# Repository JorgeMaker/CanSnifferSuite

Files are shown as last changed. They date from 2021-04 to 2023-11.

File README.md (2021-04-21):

<p align="center">
  
</p>

# CanSnifferSuite

Blue Pill CAN bus dongle is an USB to CAN Bus 2.0A/B adapter that acts as sniffer and traffic generator. This project is composed by three independent building blocks that can be used   in combination or separately.

### Firmware:
Is an application that runs on a STM32F103C8T6 and can be deployed on the [specifically designed PCB](https://github.com/JorgeMaker/CanSnifferSuite/tree/main/hw) for this project or on the popular and fairly affordable Blue Pill adding some extra HW also very cheap and easy to obtain and connect.

In this repository there are a couple of firmware. The first is for Blue Pill and is based on an interrupt driven layout design, the second in case that you prefer to use a STM32F40X family MCU uses the popular FreeRTOS for its implementation.

The [first implementation](https://github.com/JorgeMaker/CanSnifferSuite/tree/main/fw/BluePillCanSnniferEventDriven), the ISRs are responsible for receiving the basic elements of each of the two communication interfaces: the character and the datagram. Once received, they are stored in queues so that from the main function they are processed by applying a round robin algorithm.

<p align="center">
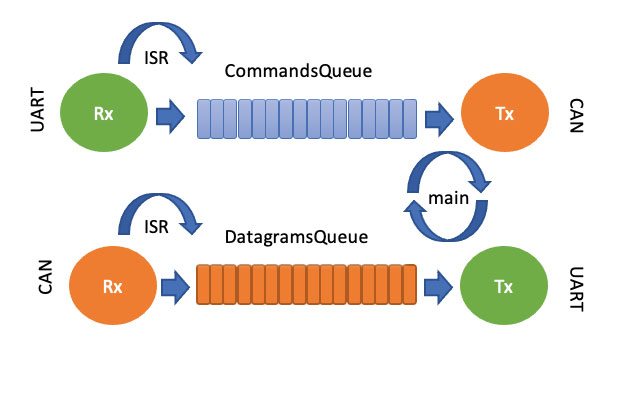
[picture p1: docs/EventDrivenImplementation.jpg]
  
</p>

The [second implementation](https://github.com/JorgeMaker/CanSnifferSuite/tree/main/fw/STM32F407VGT6CanSnniferFreeRTOS), targeted for STM32F40X uses FreeRTOS to achieve the desired functionality. The characters and datagrams received by each communication interface are stored in a pair of queues that are managed by 4 tasks.

<p align="center">
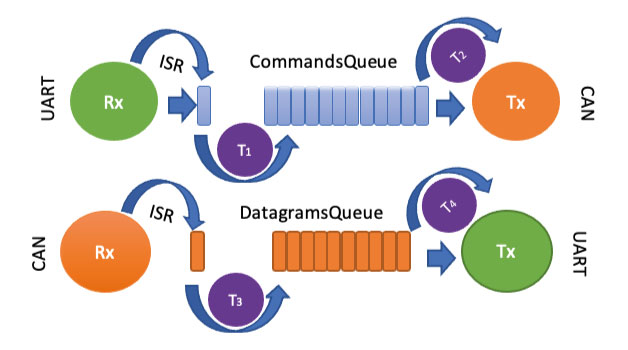
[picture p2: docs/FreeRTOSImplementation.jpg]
  
</p>

Both solutions perform the same function and can be used interchangeably  with the GUI tool and Python library.

###  Hardware:

To implement the [ HW part of the project](https://github.com/JorgeMaker/CanSnifferSuite/tree/main/hw), there are two possible alternatives with exactly the same functionality:

The first and the one the easiest reachable uses the popular very Blue Pill as MCU with an USB to TTL and a CAN bus transceiver. These three elements can be purchased online on shops like AliExpress, Banagood and others. Their combined cost does not exceed € 7, constituting a very affordable solution. There is an interconnection diagram available at the HW folder with [detailed instructions](https://github.com/JorgeMaker/CanSnifferSuite/blob/main/hw/InterconnectionsEasySolution.pdf).

The second alternative is to build custom PCB specific for this project to have a CAN bus dongle.  Geber files, and schematics are provided at the HW folder.

<p align="center">
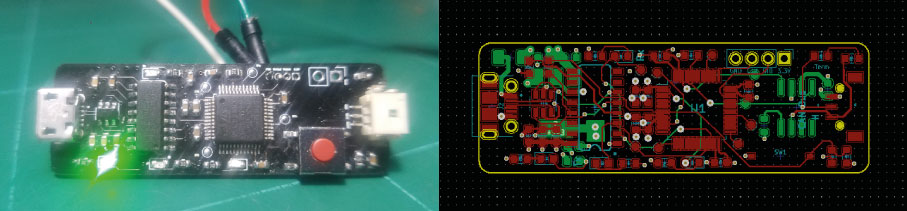
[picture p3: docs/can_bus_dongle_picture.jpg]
  
</p>

- Developed using the popular STM32F103C8T6
- Supports CAN2.0A and B, baud rates up to 500K
- 3 pins Hirose DF13 terminal: CANH, CANL, GND
- 120 Ohm termination via zero ohms resistor to enable/disable
- Tx an Rx LED indicators.
- GUI tool and Python library:

###  GUI tool and Python lib:

An application written in using PyQt/Python  has been developed. It allows communication with the Blue Pill CAN bus dongle to send commands and receive information on the traffic present on the CAN bus network acting as sniffer and traffic generator.

<p align="center">
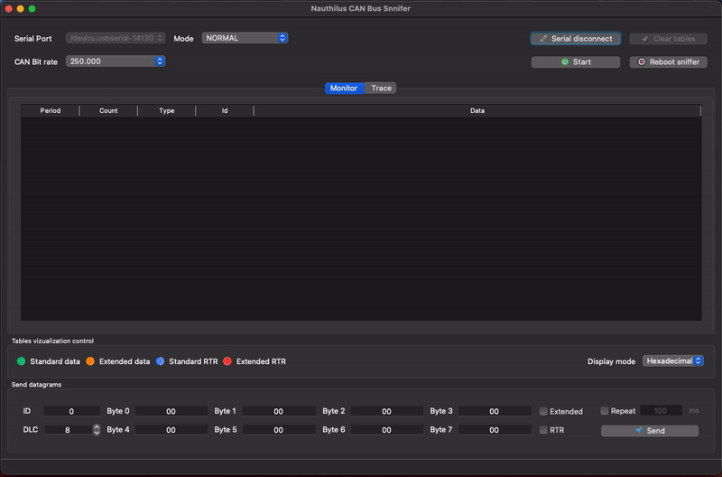
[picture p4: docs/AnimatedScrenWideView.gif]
  
</p>

The information on the traffic present on the network is parsed and sent to the application that displays it in two different formats. On the one hand, a table that lists each of the packets that have been received and, on the other, a table with the last packet received for each of the Id and the time elapsed between packets with the same ID.

It is also possible to use a Python library to write scripts that interacts with the CAN bus network as is shown in [this example](https://github.com/JorgeMaker/CanSnifferSuite/blob/main/guiApp/CanBusSnnifer/LibraryUsageDummyExample.py)

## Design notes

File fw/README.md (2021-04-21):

## Firmware:

An equivalent version of the project firmware is located in each folder. To compile on deploy it, simply download the version of your preference and import the project into CubeIDE.

- STM32F407VGT6CanSnniferFreeRTOS:  Application ready to compile and install on a STM32F407VGT6 development board, it has been developed using FreeRTOS.
- BluePillCanSnnifer:  Event driven application ready to compile and install on a STM32F103C8T6 development board or our custom board.

<p align="center">
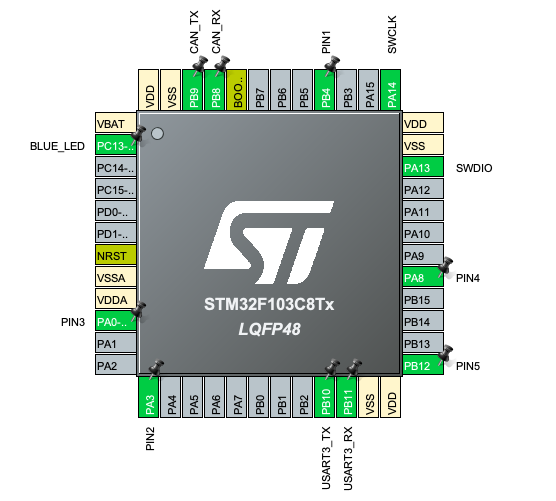
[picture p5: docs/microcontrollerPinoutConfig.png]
  
</p>

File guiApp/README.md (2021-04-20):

###  GUI tool and Python lib:

An application written in using PyQt/Python  has been developed. It allows communication with the Blue Pill CAN bus dongle to send commands and receive information on the traffic that circulates on the CAN bus acting as sniffer and traffic generator.

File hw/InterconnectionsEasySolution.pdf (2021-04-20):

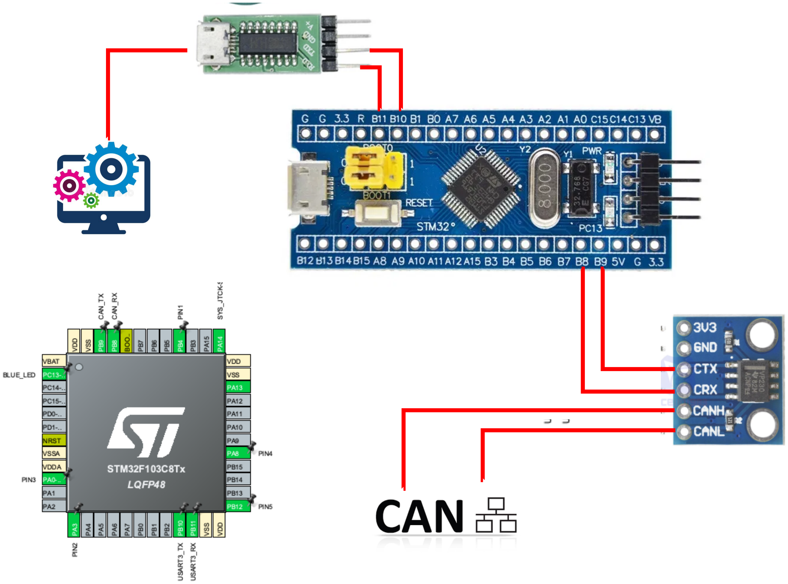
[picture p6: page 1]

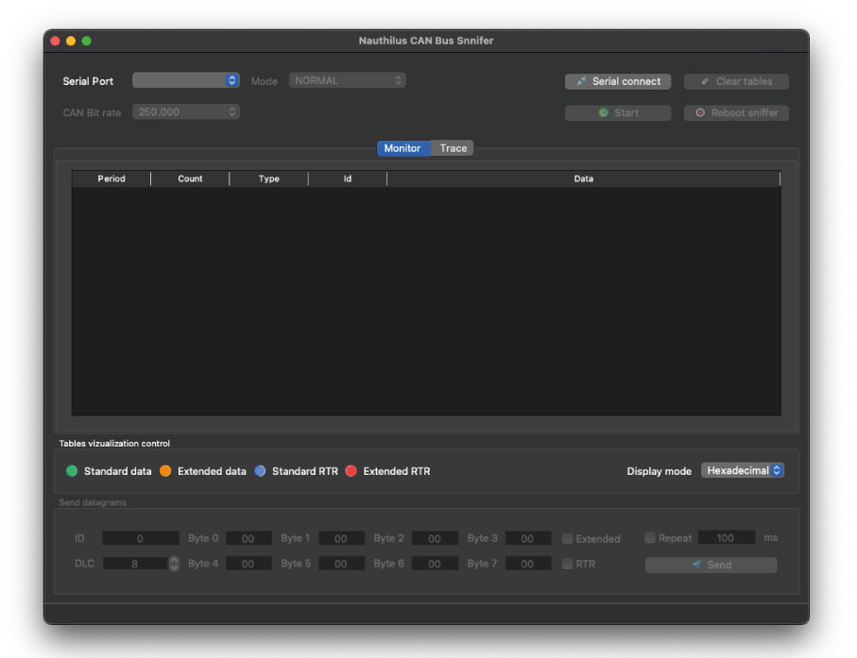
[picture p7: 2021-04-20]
docs/GUITollScreen.jpg

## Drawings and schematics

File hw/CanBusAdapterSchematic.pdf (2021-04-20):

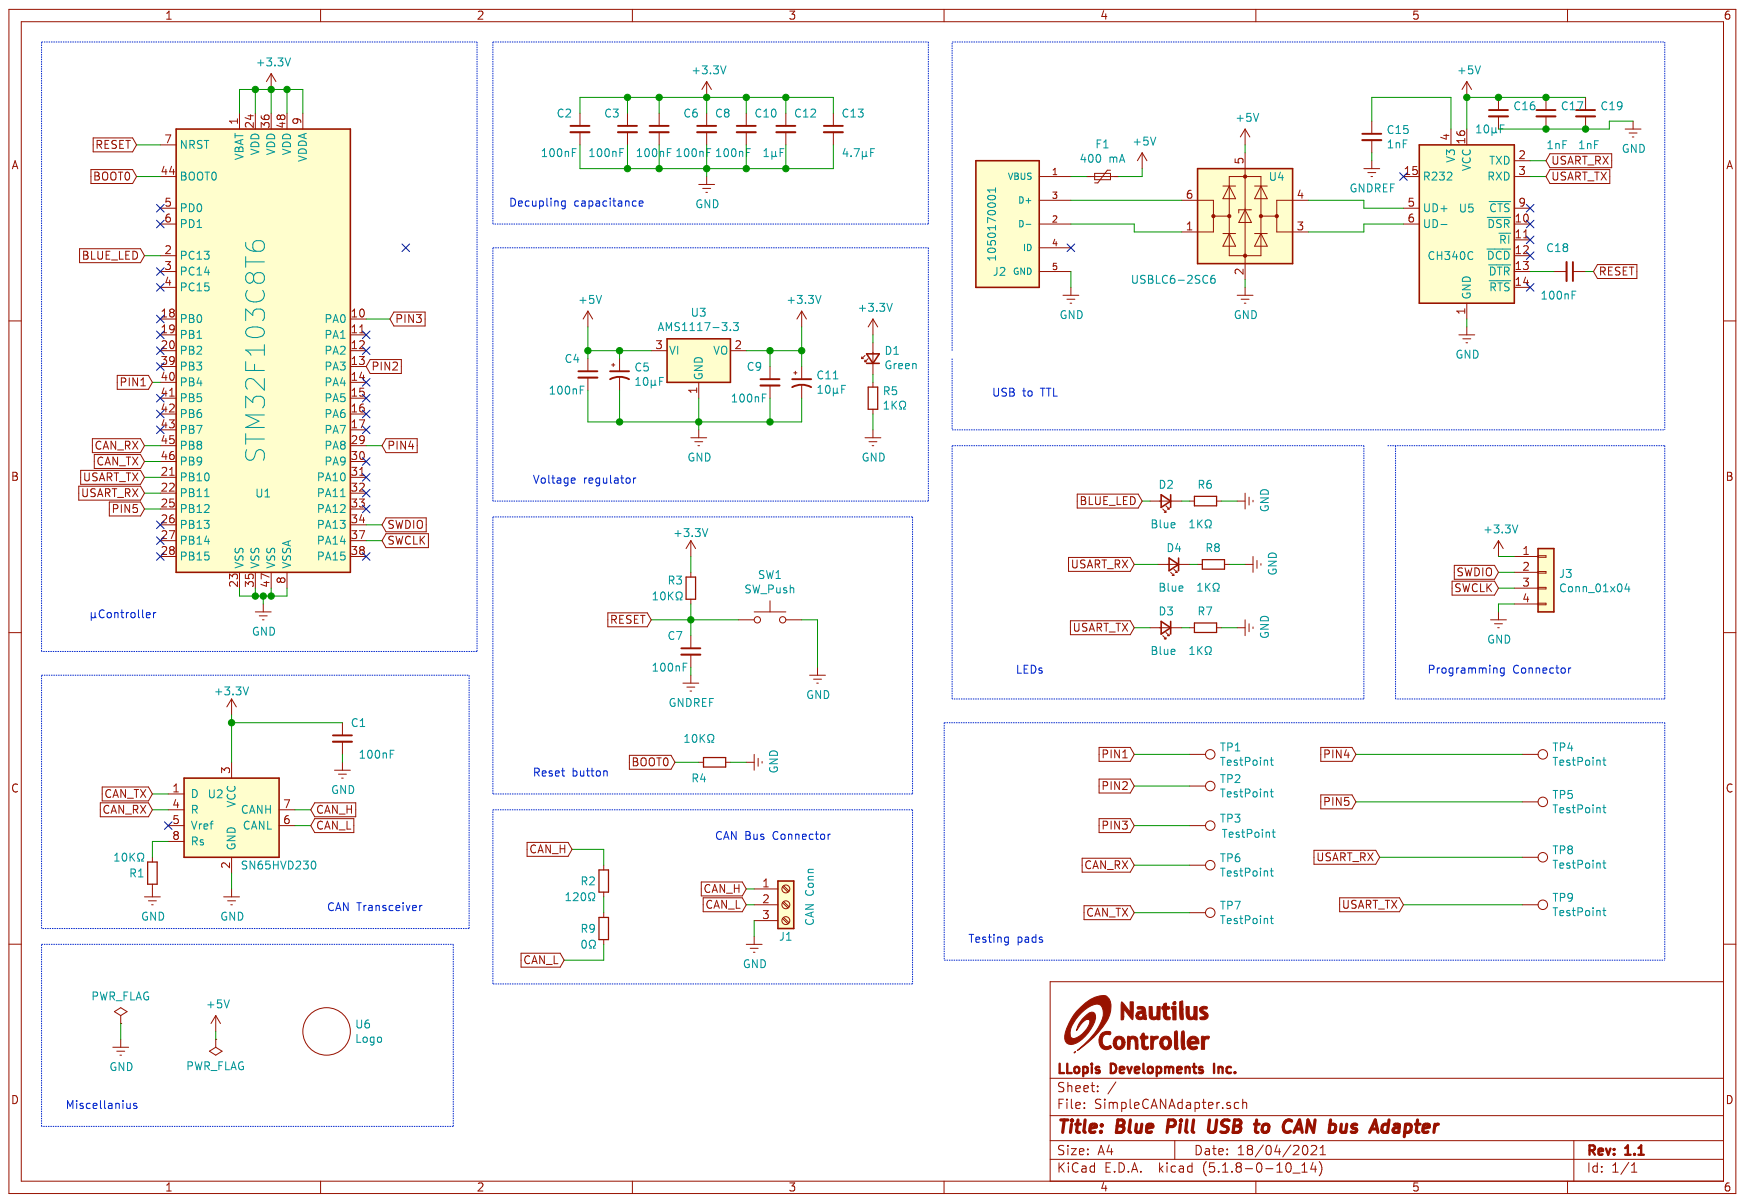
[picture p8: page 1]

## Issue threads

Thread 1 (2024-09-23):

I have a question about implementing it with the STM32 series.

cheoljun99, 2024-09-23:
Hello, I found the CanSnifferSuite project while looking for the CANSNiffer open source project. I am impressed by the project and am in the process of implementing it.

I also have a few questions. They are as follows:

1. I have a stm32f401ccu6 board, but this board does not support CAN communication. Therefore, I want to implement the project by connecting the MCP2515, but I wonder if there are any restrictions.

2. If I want to use RTOS to implement the project, do I have to use stm32f407vgt6 unconditionally, and if I want to implement it without RTOS, do I have to use stm32f103c8t6 unconditionally?

3. I am wondering if there is an alternative board that can be installed with RTOS and apply the corresponding open source code (STM32F4 series)
I am wondering if there is an alternative board that can be installed with open source code without installing RTOS (STM32F1 series)

JorgeMaker, 2024-09-25:
Hi @cheoljun99,

I'm responding to your questions below:

If your microcontroller doesn’t have native CAN communications, you'll need to implement sending and receiving CAN frames through an SPI driver that allows communication with the MCP2515. It’s completely possible to do, although it will require more work. As far as I know, there shouldn’t be any type of restriction.

Not at all, in this implementation those two microcontrollers were used simply because they were the ones I had on hand, but STM provides, through their development tools, the necessary environment to implement the functionality on any other microcontroller for which they support FreeRTOS.

The code for this project is designed to work with the STM32 HAL... it should be very easy to port it to other microcontrollers, even from different families, by adapting the Pinout and making sure everything continues to function correctly.

DISCLAIMER: The project has not been fully tested; it works correctly, but it still needs to be tested thoroughly under high message load conditions, both the Firmware part and the software part that receives the messages and displays them in the Python-implemented application.

I hope it helps !!!

Best Regards
JSLL

cheoljun99, 2024-09-25:
Hello @JorgeMaker

Thanks for your reply. It was helpful.

Best Regards,
Cheoljun

Closed 2024-09-25.

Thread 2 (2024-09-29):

Question about F407 and RTOS

ChoChiMoo, 2024-09-29:
Dear JorgeMaker

Hi,I'm student studying about can protocols and imbeded programmings.
Now I'm trying to follow your works for studying
While carry on, I have few questions.

Now I'm using stm32 F407VGT6, (dev board name STM32f407G-DISC1), I modified some fw codes to upload on board.
I'm trying to get some can packets from another device through jumper cables. (actually it connected with Rapi CAN HAT).
But I find out I cannot get any datas.

1.While trouble shooting, I wonder why USB serial use 500000baudrate, (It seems to be unusual value).
2.My ttl to usb modules using 12000 crystal, Do I have to change bitrate for serial communication?
3.I tried putty, minicom, Windows, MacOS, hercules_3-2-8. Every programs were able to make connection with board through USB, serial. But non of them succeed to get complete datas like readable strings or HEX value. Is there any reason?
4.Do you have any other advice for students trying to follow your works?

Looking forward to hearing from you soon. best regard.

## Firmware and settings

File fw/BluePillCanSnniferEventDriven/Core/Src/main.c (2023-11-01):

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
/* Includes ------------------------------------------------------------------*/
#include "main.h"

/* USER CODE BEGIN Includes */
#include "stdio.h"
#include "string.h"
#include "cobs.h"
#include "cQueue.h"
/* USER CODE END Includes */

/* USER CODE BEGIN PTD */

#define SIZE_RX 30

typedef struct qCmd {
	uint8_t commnddBuff[SIZE_RX];
	uint8_t commandSize;
} EnueuedCommand;

typedef struct qCANMsg {
	uint8_t data[8];
	CAN_RxHeaderTypeDef header;
} EncuedCANMsg;

typedef enum {
	SNIFFER_STOPPED = 0x00, SNIFFER_ACTIVE = 0x01,
} SnifferAtivityStatus;

/* USER CODE END PTD */

/* USER CODE BEGIN PD */
#define	IMPLEMENTATION	FIFO
/* USER CODE END PD */

CAN_HandleTypeDef hcan;

TIM_HandleTypeDef htim2;

UART_HandleTypeDef huart3;

/* USER CODE BEGIN PV */

// CAN Callback variables
CAN_RxHeaderTypeDef rxMessageHeader;
uint8_t rxDataReceived[8];

// UART Callback variables
uint8_t rxUARTBuff[1] = { 0 };
uint8_t rxCommandBuff[SIZE_RX] = { 0 };
volatile uint8_t cursor = 0;
uint8_t decodedCommand[SIZE_RX] = { 0 };

#define CMD_QUEUE_SIZE 100
Queue_t commandQueue;
EnueuedCommand decuedComand;

#define CAN_MSSG_QUEUE_SIZE 100
Queue_t canMsgQueue;
EncuedCANMsg decuedCANMssg;

SnifferAtivityStatus snifferAtivityStatus = SNIFFER_STOPPED;

volatile uint32_t miliseconds = 0;

/* USER CODE END PV */

void SystemClock_Config(void);
static void MX_GPIO_Init(void);
static void MX_CAN_Init(void);
static void MX_USART3_UART_Init(void);
static void MX_TIM2_Init(void);
/* USER CODE BEGIN PFP */

int __io_putchar(int);
void blueLEDIndicator(void);
void blinkLed();
void processCANMsg(void);
void processComand(void);
void processBitRateCommand();
void processMessageComand(void);
void processLoopBackModeCommand(void);
void processRebootCommand(void);
void processActivitySniferComand();
void sendCANMDummyessage(void);
uint32_t sendCANMessage(uint8_t, uint32_t, bool, bool, uint8_t*);
void setCANFilterAcceptAll(void);
void setCANFilterAcceptSingleExtendedID(uint32_t, uint32_t);
void setCANFilterAcceptSingleStandardID(uint32_t,uint16_t);
void setSinfferCANFilterAcceptRange(uint8_t, uint32_t);
void setDatagramTypeIdentifer(uint32_t, uint32_t, uint8_t*, uint8_t*);
void setFormatedDatagramIdentifer(uint32_t, uint8_t*, uint8_t*, int);
void setDatagramIdentifer(CAN_RxHeaderTypeDef, uint8_t*, uint8_t*);
void setDLC(uint32_t, uint8_t*, uint8_t*);
void setData(uint8_t*, int, uint8_t*, uint8_t*);
uint8_t serializeDatagram(uint8_t*, CAN_RxHeaderTypeDef, uint8_t*);
void HAL_CAN_RxFifo0MsgPendingCallback(CAN_HandleTypeDef*);
void processCANMsg(void);
void HAL_UART_RxCpltCallback(UART_HandleTypeDef*);
void substr(char *str, char*, int, int);
int toInteger(uint8_t *stringToConvert, int len);
void HAL_TIM_PeriodElapsedCallback(TIM_HandleTypeDef *htim);
void generateDummyCANTraffic(uint32_t);
void sendCANStdDataDummyMessage(void);
void sendCANExtDataDummyMessage(void);
void sendCANStdRemoteDummyMessage(void);
void sendCANExtRemoteDummyMessage(void);
void ErrorAppHandler(void);
/* USER CODE END PFP */

/* USER CODE BEGIN 0 */

int __io_putchar(int ch) {
	HAL_UART_Transmit(&huart3, (uint8_t*) &ch, 1, 100);
	return ch;
}
#define NUMBER_BLINKS 20
void blueLEDIndicator(void) {
	int blinkCounter = 0;
	while (blinkCounter < NUMBER_BLINKS) {
		HAL_GPIO_TogglePin(BLUE_LED_GPIO_Port, BLUE_LED_Pin);
		HAL_GPIO_TogglePin(PIN2_GPIO_Port, PIN2_Pin);
		HAL_Delay(30);
		blinkCounter++;
	}
	HAL_GPIO_WritePin(BLUE_LED_GPIO_Port, BLUE_LED_Pin, GPIO_PIN_SET);
	HAL_GPIO_WritePin(PIN2_GPIO_Port, PIN2_Pin, GPIO_PIN_SET);
}

void ErrorAppHandler(void) {
	// Display something went wrong :(
	 blueLEDIndicator();
}
/**
 * @brief  Sends a dummy message over the CAN bus using the hcan handle
 * @param  none
 * @retval None
 */
void sendCANDummyMessage(void) {
	uint32_t TxMailbox;
	CAN_TxHeaderTypeDef pHeader;
	pHeader.DLC = 8; //give message size of 1 byte
	pHeader.IDE = CAN_ID_STD; //set identifier to standard
	pHeader.RTR = CAN_RTR_DATA; //set data type to remote transmission request?CAN_RTR_DATA
	pHeader.StdId = 0x200; //define a standard identifier, used for message identification by filters (switch this for the other microcontroller)
	//uint8_t messageLoadBuffer[8] = {'B','L','A','C','K','_','&','#'};
	uint8_t messageLoadBuffer[8] = { 42, 0x4c, 0x41, 0x43, 0x4b, 0x5f, 0x26,
			0x23 };
	if (HAL_CAN_AddTxMessage(&hcan, &pHeader, messageLoadBuffer, &TxMailbox)
			!= HAL_OK) {
		ErrorAppHandler();
	}
}
/**
 * @brief  Sends a CAN message through the CAN controller
 * @param  dlc: data length code (number of bytes of data to be sent)
 * @param  msgID: ID of the message to be sent
 * @param  isRTR: flag indicating if the message is a Remote Transmission Request (RTR)
 * @param  isStandard: flag indicating if the message ID is standard (11-bit) or extended (29-bit)
 * @param  data: pointer to the data to be sent
 * @retval TxMailbox: mailbox used for transmission
 */

uint32_t sendCANMessage(uint8_t dlc, uint32_t msgID, bool isRTR,
		bool isStandard, uint8_t *data) {

	uint32_t TxMailbox;
	CAN_TxHeaderTypeDef pHeader;
	pHeader.DLC = dlc;

	if (isStandard) {
		pHeader.IDE = CAN_ID_STD;
		pHeader.StdId = msgID;
	} else {
		pHeader.IDE = CAN_ID_EXT;
		pHeader.ExtId = msgID;
	}
	if (isRTR) {
		pHeader.RTR = CAN_RTR_REMOTE;
	} else {
		pHeader.RTR = CAN_RTR_DATA;
	}

	HAL_CAN_AddTxMessage(&hcan, &pHeader, data, &TxMailbox);
	return TxMailbox;
}
/**
 * @brief  Configures the CAN filter to accept all messages to the CAN_FIFO buffer
 * @param  None
 * @retval None
 */
void setCANFilterAcceptAll(void) {
	/* Default filter - accept all to CAN_FIFO*/
	CAN_FilterTypeDef sFilterConfig;
	sFilterConfig.FilterBank = 0;
	//sFilterConfig.FilterIdHigh = 0x00005;
	sFilterConfig.FilterBank = 0x0000;
	sFilterConfig.FilterMode = CAN_FILTERMODE_IDMASK;
	sFilterConfig.FilterScale = CAN_FILTERSCALE_32BIT;
	// Set Mask to all 0s to allow pass any messageID
	sFilterConfig.FilterMaskIdHigh = 0x0000;
	sFilterConfig.FilterMaskIdLow = 0x0000;
	sFilterConfig.FilterFIFOAssignment = CAN_FILTER_FIFO0;
	sFilterConfig.FilterActivation = ENABLE;
	if (HAL_CAN_ConfigFilter(&hcan, &sFilterConfig) != HAL_OK) {
		ErrorAppHandler();
	}
}


void setCANFilterAcceptSingleStandardID(uint32_t filterBank, uint16_t acceptedID){
	/* Default filter - accept all to CAN_FIFO*/
	CAN_FilterTypeDef sFilterConfig;
	sFilterConfig.FilterBank = 0;
	sFilterConfig.FilterBank = filterBank;
	sFilterConfig.FilterMode = CAN_FILTERMODE_IDMASK;
	sFilterConfig.FilterScale = CAN_FILTERSCALE_32BIT;
	sFilterConfig.FilterIdHigh = acceptedID << 5; //11-bit ID, in top bits 6= 16-11 bits
	sFilterConfig.FilterIdLow = 0x0000;
	sFilterConfig.FilterMaskIdHigh = 0x7FF << 5;
	sFilterConfig.FilterMaskIdLow = 0x0000;
	sFilterConfig.FilterFIFOAssignment = CAN_FILTER_FIFO0;
	sFilterConfig.FilterActivation = ENABLE;
	if (HAL_CAN_ConfigFilter(&hcan, &sFilterConfig) != HAL_OK) {
		ErrorAppHandler();
	}
}




void setCANFilterAcceptSingleExtendedID(uint32_t filterBank, uint32_t acceptedID){
	uint16_t low16bits = acceptedID & 0xFFFF;
	uint16_t high16Bits = (acceptedID >> 16) & 0xFFFF;
    /* Default filter - accept all to CAN_FIFO*/
	CAN_FilterTypeDef sFilterConfig;
	sFilterConfig.FilterBank = 0;
	sFilterConfig.FilterBank = filterBank;
	sFilterConfig.FilterMode = CAN_FILTERMODE_IDMASK;
	sFilterConfig.FilterScale = CAN_FILTERSCALE_32BIT;
	sFilterConfig.FilterIdHigh = high16Bits;
	sFilterConfig.FilterIdLow = low16bits << 3; //11-bit ID, in top bits 3=(32-29)
	sFilterConfig.FilterMaskIdHigh = 0xFFFF;
	sFilterConfig.FilterMaskIdLow = 0xFFF8;
	sFilterConfig.FilterFIFOAssignment = CAN_FILTER_FIFO0;
	sFilterConfig.FilterActivation = ENABLE;
	if (HAL_CAN_ConfigFilter(&hcan, &sFilterConfig) != HAL_OK) {
		ErrorAppHandler();
	}
}

/**
 * setDatagramTypeIdentifier
 *
 * @brief sets the type identifier of a CAN (Controller Area Network) datagram
 *
 * This function takes in four parameters:
 * - ide: an unsigned 32-bit integer representing the ID format of the datagram (either CAN_ID_STD for standard ID format or CAN_ID_EXT for extended ID format)
 * - rtr: an unsigned 32-bit integer representing the type of the datagram (either CAN_RTR_DATA for data frame or CAN_RTR_REMOTE for remote frame)
 * - pExitBuffer: a pointer to the buffer where the datagram will be stored
 * - pCursor: a pointer to an integer representing the current position of the cursor in the buffer
 *
 * The function first checks the value of ide to determine whether the datagram uses a standard or extended ID format.
 * If ide is CAN_ID_STD, the function checks the value of rtr to determine whether the datagram is a data or remote frame.
 * If rtr is CAN_RTR_DATA, the function sets the first byte of the datagram to 't' and if rtr is CAN_RTR_REMOTE,
 * the function sets the first byte of the datagram to 'r'.
 *
 * If ide is CAN_ID_EXT, the function again checks the value of rtr to determine whether the datagram is a data or remote frame.
 * If rtr is CAN_RTR_DATA, the function sets the first byte of the datagram to 'T' and if rtr is CAN_RTR_REMOTE,
 * the function sets the first byte of the datagram to 'R'.
 *
 * Finally, the function increments the cursor position by 1.
 *
 * @param ide - unsigned 32-bit int, representing the ID format of the datagram
 * @param rtr - unsigned 32-bit int, representing the type of the datagram
 * @param pExitBuffer - pointer to the buffer where the datagram will be stored
 * @param pCursor - pointer to an integer representing the current position of the cursor in the buffer
 *
 * @return void
 */
void setDatagramTypeIdentifer(uint32_t ide, uint32_t rtr, uint8_t *pExitBuffer,
		uint8_t *pCursor) {
	if (ide == CAN_ID_STD) {
		if (rtr == CAN_RTR_DATA) {
			pExitBuffer[*pCursor] = 't';
		} else if (rtr == CAN_RTR_REMOTE) {
			pExitBuffer[*pCursor] = 'r';
		}
	} else if (ide == CAN_ID_EXT) {

		if (rtr == CAN_RTR_DATA) {
			pExitBuffer[*pCursor] = 'T';
		} else if (rtr == CAN_RTR_REMOTE) {
			pExitBuffer[*pCursor] = 'R';
		}
	}
	*pCursor = *pCursor + 1;
}
/**
* @brief  Formats a given ID number and copies it to a buffer at a specific cursor position
* @param  idNum: the ID number to be formatted and copied
* @param  pExitBuffer: pointer to the buffer where the formatted ID will be copied
* @param  pCursor: pointer to the cursor position in the buffer
* @param  len: the desired length of the formatted ID
* @retval None
*/
void setFormatedDatagramIdentifer(uint32_t idNum, uint8_t *pExitBuffer,uint8_t *pCursor, int len) {

	char *id = (char*) malloc(sizeof(char) * (len + 1));
	int numOfDigits = 0;
	int valueToConsume = idNum;

	while (valueToConsume != 0) {
		valueToConsume /= 10;     // n = n/10
		++numOfDigits;
	}

	sprintf(id + (len - numOfDigits), "%d", (int) idNum);
	for (int eraser = 0; eraser < (len - numOfDigits); eraser++) {
		id[eraser] = '0';
	}
	memcpy((char*) pExitBuffer + *pCursor, id, strlen(id)+1);
	free(id);
	*pCursor = *pCursor + len;
}
/**
* @brief  Extracts the ID of a received CAN message and formats it to a desired length, then copies it to
*         a buffer at a specific cursor position
* @param  receivedCANHeader: the header of the received CAN message, containing the ID of the message
* @param  pExitBuffer: pointer to the buffer where the formatted ID will be copied
* @param  pCursor: pointer to the cursor position in the buffer
* @retval None
*/
void setDatagramIdentifer(CAN_RxHeaderTypeDef receivedCANHeader,
		uint8_t *pExitBuffer, uint8_t *pCursor) {
	if (receivedCANHeader.IDE == CAN_ID_EXT) {
		setFormatedDatagramIdentifer(receivedCANHeader.ExtId, pExitBuffer,
				pCursor, 9);
	}
	if (receivedCANHeader.IDE == CAN_ID_STD) {
		setFormatedDatagramIdentifer(receivedCANHeader.StdId, pExitBuffer,
				pCursor, 4);

	}
}
/**
 * @brief  Formats and copies the data length code (DLC) of a received CAN message to a buffer at a specific cursor position
 * @param  dlc: the data length code of the received message
 * @param  pExitBuffer: pointer to the buffer where the DLC will be copied
 * @param  pCursor: pointer to the cursor position in the buffer
 * @retval None
 */
void setDLC(uint32_t dlc, uint8_t *pExitBuffer, uint8_t *pCursor) {
    sprintf((char*) pExitBuffer + *pCursor, "%d", (int) dlc);
	*pCursor = *pCursor + 1;
}
/**
 * @brief  Copy data from source to destination buffer at specific cursor position
 * @param  data: pointer to the source data
 * @param  dlc: data length code
 * @param  pExitBuffer: pointer to the destination buffer
 * @param  pCursor: pointer to the cursor position in the destination buffer
 * @retval None
 */
void setData(uint8_t *data, int dlc, uint8_t *pExitBuffer, uint8_t *pCursor) {
	for (int counter = 0; counter < dlc; counter++) {
		pExitBuffer[*pCursor + counter] = data[counter];
	}
	*pCursor = *pCursor + dlc;
}
/**
 * @brief Serialize a CAN datagram and store it in a buffer
 * @param pExitBuffer: pointer to the buffer where the serialized datagram will be stored
 * @param receivedCANHeader: struct containing the header information of the received CAN message
 * @param rxData: pointer to the received data payload
 * @retval cursor: the final position of the cursor in the buffer
 */
uint8_t serializeDatagram(uint8_t *pExitBuffer,
		CAN_RxHeaderTypeDef receivedCANHeader, uint8_t *rxData) {

	uint8_t cursor = 0;
	setDatagramTypeIdentifer(receivedCANHeader.IDE, receivedCANHeader.RTR,
			pExitBuffer, &cursor);
	setDatagramIdentifer(receivedCANHeader, pExitBuffer, &cursor);
	setDLC(receivedCANHeader.DLC, pExitBuffer, &cursor);
	if (receivedCANHeader.RTR == CAN_RTR_DATA) {
		setData(rxData, receivedCANHeader.DLC, pExitBuffer, &cursor);
	}

	return cursor;
}

#define ZERO_BYTE '0x00'

/**
 * @brief Interrupt callback function for CAN RX FIFO0 message pending. For each received Messsge a new
 *        EncuedCANMsg is created and stored in the Queue to be processed when corresponding
 * @param hcan: pointer to the CAN handle
 * @retval None
 */
void HAL_CAN_RxFifo0MsgPendingCallback(CAN_HandleTypeDef *hcan) {
	if (HAL_CAN_GetRxMessage(hcan, CAN_RX_FIFO0, &rxMessageHeader,rxDataReceived) == HAL_OK) {
		HAL_GPIO_TogglePin(PIN3_GPIO_Port, PIN3_Pin);
		EncuedCANMsg msg;
		msg.header = rxMessageHeader;
		memcpy((char*) msg.data, (char*) rxDataReceived,rxMessageHeader.DLC);
		q_push(&canMsgQueue, &msg);
	} else {
		ErrorAppHandler();
	}

}
/**
 * @brief Process a received CAN message extracted from the Queue serializing it and then
 *        applying COBS encoding to sent it using UART
 * @retval None
 */
void processCANMsg() {

	uint8_t parsedDatagram[24] = { 0 };
	uint8_t lenParsed = serializeDatagram(parsedDatagram, decuedCANMssg.header,
			decuedCANMssg.data);

	uint8_t encodedDatagram[24] = { 0 };
	cobs_encode_result result = cobs_encode(encodedDatagram, 24, parsedDatagram,
			lenParsed + 1);

	if (result.status == COBS_ENCODE_OK) {
		// Append Zero byte to delimiter frame boundary
		encodedDatagram[result.out_len + 1] = 0x00;
		HAL_UART_Transmit(&huart3, encodedDatagram, result.out_len + 1, 50);

		// Toggle monitoring line to indicate a successful datagram retransmission
		HAL_GPIO_TogglePin(PIN2_GPIO_Port, PIN2_Pin);
	}
}

#define NUMBER_BOOT_BLINKS 5

void blinkLed() {
	int blinkCounter = 0;
	while (blinkCounter < NUMBER_BOOT_BLINKS) {
		HAL_GPIO_TogglePin(BLUE_LED_GPIO_Port, BLUE_LED_Pin);
		HAL_Delay(50);
		blinkCounter++;
	}
	HAL_GPIO_WritePin(BLUE_LED_GPIO_Port, BLUE_LED_Pin, GPIO_PIN_SET);
}
/**
 * @brief Interrupt callback function for UART RX Complete event. each time a new bute is recived is
 *        processed and stored inside rxCommandBuff until the last character is received and then the
 *        rxCommandBuff is used t create a new EnueuedCommand that is stored ant te Queue pending to
 *        be processed.
 * @param huart: pointer to the UART handle
 * @retval None
 */
void HAL_UART_RxCpltCallback(UART_HandleTypeDef *huart) {
	if (huart->Instance == huart3.Instance) {
		HAL_GPIO_TogglePin(PIN1_GPIO_Port, PIN1_Pin);
		rxCommandBuff[cursor] = rxUARTBuff[0];
		cursor++;
		if (cursor >= SIZE_RX) {
			cursor = 0;
		}
		if (rxUARTBuff[0] == 0x00) {
			EnueuedCommand pendingCmd;
			memcpy((char*) pendingCmd.commnddBuff, (char*) rxCommandBuff, cursor);
			pendingCmd.commandSize = cursor - 1;
			if (!q_isFull(&commandQueue)) {
				q_push(&commandQueue, &pendingCmd);
			}
			cursor = 0;
			HAL_GPIO_TogglePin(PIN2_GPIO_Port, PIN2_Pin);
		}
		// Enable interrupt for again to be able to continue receiving data
		HAL_UART_Receive_IT(&huart3, rxUARTBuff, 1);
	}

}
/**
 * @brief Extracts a substring from a string
 * @param str: pointer to the original string
 * @param sub: pointer to the substring buffer
 * @param start: starting index of the substring
 * @param len: length of the substring
 * @retval None
 */
void substr(char *str, char *sub, int start, int len) {
	memcpy(sub, &str[start], len);
	sub[len] = '\0';
}
/**
 * @brief Converts a string of digits to an integer
 * @param stringToConvert: pointer to the string of digits
 * @param len: length of the string
 * @retval The integer value of the string
 */
int toInteger(uint8_t *stringToConvert, int len) {
	int counter = len - 1;
	int exp = 1;
	int value = 0;
	while (counter >= 0) {
		value = value + (stringToConvert[counter] - '0') * exp;
		exp = exp * 10;
		counter--;
	}
	return value;
}
/**
 * @brief Process each Message command received from  the UART interface and
 *        send the apropiate CAN Message.
 * @retval None
 * @retval None
 */
void processMessageComand() {
	uint8_t cursor = 1;

	if (decodedCommand[cursor] == 'T') {
		cursor++;
		uint8_t messageID_str[9];
		substr((char*) decodedCommand, (char*) messageID_str, cursor, 9);

		int msgID = toInteger(messageID_str, 9);
		cursor += 9;

		uint8_t dlc_str[1];
		substr((char*) decodedCommand, (char*) dlc_str, cursor, 1);
		uint8_t dlc = atoi((char*) dlc_str);

		cursor++;
		uint8_t data[8];
		substr((char*) decodedCommand, (char*) data, cursor, 8);

		sendCANMessage(dlc, msgID, false, false, data);

	} else if (decodedCommand[cursor] == 'R') {
		cursor++;
		uint8_t messageID_str[9];
		substr((char*) decodedCommand, (char*) messageID_str, cursor, 9);

		int msgID = toInteger(messageID_str, 9);
		cursor += 9;

		uint8_t dlc_str[1];
		substr((char*) decodedCommand, (char*) dlc_str, cursor, 1);
		uint8_t dlc = toInteger(dlc_str, 1);

		sendCANMessage(dlc, msgID, true, false, 0x00);
	} else if (decodedCommand[cursor] == 't') {
		cursor++;
		uint8_t messageID_str[4];
		substr((char*) decodedCommand, (char*) messageID_str, cursor, 4);
		int msgID = toInteger(messageID_str, 4);
		cursor += 4;

		uint8_t dlc_str[1];
		substr((char*) decodedCommand, (char*) dlc_str, cursor, 1);
		uint8_t dlc = toInteger(dlc_str, 1);

		cursor++;
		uint8_t data[8];
		substr((char*) decodedCommand, (char*) data, cursor, 8);

		sendCANMessage(dlc, msgID, false, true, data);

	} else if (decodedCommand[cursor] == 'r') {
		cursor++;
		uint8_t messageID_str[4];
		substr((char*) decodedCommand, (char*) messageID_str, cursor, 4);
		int msgID = toInteger(messageID_str, 4);
		cursor += 4;

		uint8_t dlc_str[1];
		substr((char*) decodedCommand, (char*) dlc_str, cursor, 1);
		uint8_t dlc = atoi((char*) dlc_str);

		sendCANMessage(dlc, msgID, true, true, 0x00);
	}

}

void processBitRateCommand() {
	uint8_t bitrateSrt[3];
	substr((char*) decodedCommand, (char*) bitrateSrt, 1, 3);
	int bitRate = toInteger(bitrateSrt, 3);

	bool idetified = false;

	switch (bitRate) {
	case 10:
		hcan.Init.Prescaler = 200;
		idetified = true;
		break;
	case 20:
		hcan.Init.Prescaler = 100;
		idetified = true;
		break;
	case 50:
		hcan.Init.Prescaler = 40;
		idetified = true;
		break;
	case 100:
		hcan.Init.Prescaler = 20;
		idetified = true;
		break;
	case 125:
		hcan.Init.Prescaler = 16;
		idetified = true;
		break;
	case 250:
		hcan.Init.Prescaler = 8;
		idetified = true;
		break;
	case 500:
		hcan.Init.Prescaler = 4;
		idetified = true;
		break;
	case 1000:
		hcan.Init.Prescaler = 2;
		idetified = true;
		break;
	}
	if (idetified) {
		if (HAL_CAN_DeInit(&hcan) != HAL_OK) {
			ErrorAppHandler();
		}
		if (HAL_CAN_Init(&hcan) != HAL_OK) {
			ErrorAppHandler();
		}
		setCANFilterAcceptAll();
		if (HAL_CAN_Start(&hcan) != HAL_OK) {
			ErrorAppHandler();
		}
		if (snifferAtivityStatus != SNIFFER_STOPPED) {
			if (HAL_CAN_ActivateNotification(&hcan, CAN_IT_RX_FIFO0_MSG_PENDING)
					!= HAL_OK) {
				ErrorAppHandler();
			}
		}
	}
}
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
int main(void)
{
  /* MCU Configuration--------------------------------------------------------*/

  /* Reset of all peripherals, Initializes the Flash interface and the Systick. */
  HAL_Init();

  /* Configure the system clock */
  SystemClock_Config();

  /* Initialize all configured peripherals */
  MX_GPIO_Init();
  MX_CAN_Init();
  MX_USART3_UART_Init();
  MX_TIM2_Init();
  /* USER CODE BEGIN 2 */
	// Enable interrupt for to be able to receiving data via UART
	HAL_UART_Receive_IT(&huart3, rxUARTBuff, 1);
	// Set CAN Filter to receive all messages
	setCANFilterAcceptAll();
	HAL_CAN_Start(&hcan);
	if (snifferAtivityStatus != SNIFFER_STOPPED) {
		HAL_CAN_ActivateNotification(&hcan, CAN_IT_RX_FIFO0_MSG_PENDING);
	}
	// Initialize EncuedCANMsg
	q_init(&canMsgQueue, sizeof(EncuedCANMsg), CAN_MSSG_QUEUE_SIZE,
			IMPLEMENTATION, false);
	// Initialize EnueuedCommand
	q_init(&commandQueue, sizeof(EnueuedCommand), CMD_QUEUE_SIZE,
			IMPLEMENTATION, true);
	// Displays we are starting the main loop
	blueLEDIndicator();
	HAL_TIM_Base_Start_IT(&htim2);
  /* USER CODE END 2 */

  /* Infinite loop */
  /* USER CODE BEGIN WHILE */
	while (1) {
    /* USER CODE END WHILE */

    /* USER CODE BEGIN 3 */

		// Use this function to make it a a dummy traffic generator
		//generateDummyCANTraffic(10);

		if (q_pop(&commandQueue, &decuedComand)) {
			processComand();
		}
		if (q_pop(&canMsgQueue, &decuedCANMssg)) {
			processCANMsg();
		}

	}
  /* USER CODE END 3 */
}

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


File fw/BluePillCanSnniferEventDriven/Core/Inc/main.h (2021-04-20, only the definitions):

#define BLUE_LED_Pin GPIO_PIN_13
#define BLUE_LED_GPIO_Port GPIOC
#define PIN3_Pin GPIO_PIN_0
#define PIN3_GPIO_Port GPIOA
#define PIN2_Pin GPIO_PIN_3
#define PIN2_GPIO_Port GPIOA
#define PIN5_Pin GPIO_PIN_12
#define PIN5_GPIO_Port GPIOB
#define PIN4_Pin GPIO_PIN_8
#define PIN4_GPIO_Port GPIOA
#define PIN1_Pin GPIO_PIN_4
#define PIN1_GPIO_Port GPIOB

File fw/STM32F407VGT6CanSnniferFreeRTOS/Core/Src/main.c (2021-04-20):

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
/* Includes ------------------------------------------------------------------*/
#include "main.h"
#include "cmsis_os.h"

/* USER CODE BEGIN Includes */
#include "stdio.h"
#include "string.h"
#include "cobs.h"
#include "stdbool.h"

/* USER CODE END Includes */

/* USER CODE BEGIN PTD */
typedef struct qCmd {
	uint8_t commnddBuff[20];
	uint8_t commandSize;
} SnniferCommand;

typedef struct qCANMsg {
	uint8_t data[8];
	CAN_RxHeaderTypeDef header;
} CANMessage;

typedef enum {
	SNIFFER_STOPPED = 0x00, SNIFFER_ACTIVE = 0x01,
} SnifferAtivityStatus;

/* USER CODE END PTD */

/* USER CODE BEGIN PD */
#define osAnySignal 0x00
#define SIZE_RX 20
#define noWait 0
/* USER CODE END PD */

CAN_HandleTypeDef hcan1;
UART_HandleTypeDef huart1;

/* USER CODE BEGIN PV */

osThreadId receiveCommandsTaskId;
osThreadId executeCommmandtaskID;
osThreadId forwardDatagramTaskId;
osThreadId receivedDatagramTaskId;

osThreadId idleTaskId;

osMailQDef(pendingCommandsQueue, 100, SnniferCommand); // Define pendingCommandsQueue
osMailQId pendingCommandsQueue;

osMailQDef(canDatagramsQueue, 100, CANMessage);		// Define mail queue
osMailQId canDatagramsQueue;

// Peripherals ISR global variables
uint8_t rxUARTBuff[1] = { 0 };

CAN_RxHeaderTypeDef rxMessageHeader;
uint8_t rxDataReceived[8];



// Sneffer activity status variable
SnifferAtivityStatus snifferAtivityStatus = SNIFFER_STOPPED;

/* USER CODE END PV */

void SystemClock_Config(void);
static void MX_GPIO_Init(void);
static void MX_CAN1_Init(void);
static void MX_USART1_UART_Init(void);
void StartDefaultTask(void const *argument);

/* USER CODE BEGIN PFP */
void bootLEDIndicator(void);

void executeCommandThread(void const*);
void rcvCommandThread(void const*);
void fordwardDatagramsThread(void const*);
void recieivedDatagramsThread(void const*);
void idleThread(void const*);

/* USER CODE END PFP */

/* USER CODE BEGIN 0 */
#define NUMBER_BLINKS 20

void bootLEDIndicator(void) {
	int blinkCounter = 0;
	while (blinkCounter < NUMBER_BLINKS) {
		HAL_GPIO_TogglePin(ORANGE_LED_GPIO_Port, ORANGE_LED_Pin);
		HAL_Delay(30);
		blinkCounter++;
	}
	HAL_GPIO_WritePin(ORANGE_LED_GPIO_Port, ORANGE_LED_Pin, GPIO_PIN_SET);
}
void substr(char *str, char *sub, int start, int len) {
	memcpy(sub, &str[start], len);
	sub[len] = '\0';
}

int toInteger(uint8_t *stringToConvert, int len) {
	int counter = len - 1;
	int exp = 1;
	int value = 0;
	while (counter >= 0) {
		value = value + (stringToConvert[counter] - '0') * exp;
		exp = exp * 10;
		counter--;
	}
	return value;
}
uint32_t sendCANMessage(uint8_t dlc, uint32_t msgID, bool isRTR,bool isStandard, uint8_t *data) {

	uint32_t TxMailbox;
	CAN_TxHeaderTypeDef pHeader;
	pHeader.DLC = dlc;

	if (isStandard) {
		pHeader.IDE = CAN_ID_STD;
		pHeader.StdId = msgID;
	} else {
		pHeader.IDE = CAN_ID_EXT;
		pHeader.ExtId = msgID;
	}
	if (isRTR) {
		pHeader.RTR = CAN_RTR_REMOTE;
	} else {
		pHeader.RTR = CAN_RTR_DATA;
	}

	HAL_CAN_AddTxMessage(&hcan1, &pHeader, data, &TxMailbox);
	return TxMailbox;
}

void setSinfferCANFilter(void) {
	/* Default filter - accept all to CAN_FIFO*/
	CAN_FilterTypeDef sFilterConfig;
	sFilterConfig.FilterBank = 0;
	sFilterConfig.FilterIdHigh = 0x00005;
	sFilterConfig.FilterBank = 0x0000;
	sFilterConfig.FilterMode = CAN_FILTERMODE_IDMASK;
	sFilterConfig.FilterScale = CAN_FILTERSCALE_32BIT;
	sFilterConfig.FilterIdHigh = 0x200 << 5;  //11-bit ID, in top bits
	sFilterConfig.FilterIdLow = 0x0000;
	sFilterConfig.FilterMaskIdHigh = 0x0000;
	sFilterConfig.FilterMaskIdLow = 0x0000;
	sFilterConfig.FilterFIFOAssignment = CAN_FILTER_FIFO0;
	sFilterConfig.FilterActivation = ENABLE;

	HAL_CAN_ConfigFilter(&hcan1, &sFilterConfig);
}

void processMessageComand(char *decodedCommand) {
	uint8_t cursor = 1;

	if (decodedCommand[cursor] == 'T') {
		cursor++;
		uint8_t messageID_str[9];
		substr((char*) decodedCommand, (char*) messageID_str, cursor, 9);

		int msgID = toInteger(messageID_str, 9);
		cursor += 9;

		uint8_t dlc_str[1];
		substr((char*) decodedCommand, (char*) dlc_str, cursor, 1);
		uint8_t dlc = atoi((char*) dlc_str);

		cursor++;
		uint8_t data[8];
		substr((char*) decodedCommand, (char*) data, cursor, 8);

		sendCANMessage(dlc, msgID, false, false, data);

	} else if (decodedCommand[cursor] == 'R') {
		cursor++;
		uint8_t messageID_str[9];
		substr((char*) decodedCommand, (char*) messageID_str, cursor, 9);

		int msgID = toInteger(messageID_str, 9);
		cursor += 9;

		uint8_t dlc_str[1];
		substr((char*) decodedCommand, (char*) dlc_str, cursor, 1);
		uint8_t dlc = toInteger(dlc_str, 1);

		sendCANMessage(dlc, msgID, true, false, 0x00);
	} else if (decodedCommand[cursor] == 't') {
		cursor++;
		uint8_t messageID_str[4];
		substr((char*) decodedCommand, (char*) messageID_str, cursor, 4);
		int msgID = toInteger(messageID_str, 4);
		cursor += 4;

		uint8_t dlc_str[1];
		substr((char*) decodedCommand, (char*) dlc_str, cursor, 1);
		uint8_t dlc = toInteger(dlc_str, 1);

		cursor++;
		uint8_t data[8];
		substr((char*) decodedCommand, (char*) data, cursor, 8);

		sendCANMessage(dlc, msgID, false, true, data);

	} else if (decodedCommand[cursor] == 'r') {
		cursor++;
		uint8_t messageID_str[4];
		substr((char*) decodedCommand, (char*) messageID_str, cursor, 4);
		int msgID = toInteger(messageID_str, 4);
		cursor += 4;

		uint8_t dlc_str[1];
		substr((char*) decodedCommand, (char*) dlc_str, cursor, 1);
		uint8_t dlc = atoi((char*) dlc_str);

		sendCANMessage(dlc, msgID, true, true, 0x00);
	}

}

void processBitRateCommand(char *decodedCommand) {

	uint8_t bitrateSrt[3];
	substr((char*) decodedCommand, (char*) bitrateSrt, 1, 3);
	int bitRate = toInteger(bitrateSrt, 3);

	bool idetified = false;

	switch (bitRate) {
	case 10:
		hcan1.Init.Prescaler = 300;
		idetified = true;
		break;
	case 20:
		hcan1.Init.Prescaler = 150;
		idetified = true;
		break;
	case 50:
		hcan1.Init.Prescaler = 60;
		idetified = true;
		break;
	case 100:
		hcan1.Init.Prescaler = 30;
		idetified = true;
		break;
	case 125:
		hcan1.Init.Prescaler = 24;
		idetified = true;
		break;
	case 250:
		hcan1.Init.Prescaler = 12;
		idetified = true;
		break;
	case 500:
		hcan1.Init.Prescaler = 6;
		idetified = true;
		break;
	}
	if (idetified) {
		HAL_CAN_DeInit(&hcan1);
		HAL_CAN_Init(&hcan1);
		setSinfferCANFilter();
		HAL_CAN_Start(&hcan1);
		if (snifferAtivityStatus != SNIFFER_STOPPED) {
			HAL_CAN_ActivateNotification(&hcan1, CAN_IT_RX_FIFO0_MSG_PENDING);
		}
	}
}
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

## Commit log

2021-04-20 Initial commit :)
    [SimpleCANAdapter-B_Cu.gbr, SimpleCANAdapter-B_Mask.gbr, SimpleCANAdapter-B_Paste.gbr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]
2021-04-21 File directory improvements
    [SimpleCANAdapter-B_Cu.gbr, SimpleCANAdapter-B_Mask.gbr, SimpleCANAdapter-B_Paste.gbr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]
2021-06-30 change strcpy to memcpy
    Modification due to a bug causing not working properly with /0 on payload
    [BluePillCanSnnifer.ioc, main.c]
2023-01-19 CAN filter improvements
    Added functionality to filter messages based on a dingle messageID
2023-03-07 Addition of NautilusDatagram
    NautilusDatagram allows communication with Nutilus BLDC Driver using CAN Bus protocol
2023-11-01 Issue sending Extended frames longer than 5 bytes
    + Solved issue with RX command buffer. Changed from 20 to 25 in order to be able to send Extended messages
    [main.c]

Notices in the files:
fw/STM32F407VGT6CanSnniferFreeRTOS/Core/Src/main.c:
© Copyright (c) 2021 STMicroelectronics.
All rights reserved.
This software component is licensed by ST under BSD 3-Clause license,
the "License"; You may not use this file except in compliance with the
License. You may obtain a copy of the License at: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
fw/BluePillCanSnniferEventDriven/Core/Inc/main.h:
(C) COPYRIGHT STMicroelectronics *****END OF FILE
